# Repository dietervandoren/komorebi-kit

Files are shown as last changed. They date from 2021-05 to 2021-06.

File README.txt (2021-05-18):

//~~~~~~~~~~~~~~~~~~~~~~~~~~~~~~~~~~~~~~~~~~~~~~~~~~~~~~~~~~~~~~~~~~~~~~~~~~~~~
//
// KOMOREBI KIT, 2021 
//
// Created by Matteo Marangoni & Dieter Vandoren 
// Programming by Riccardo Marogna
// PCB design by Daan Johan 
//
// Info & documentation: https://instrumentinventors.org/editions/iii-sensory-kit-komorebi-instructions/ 
// GitHub: https://github.com/dietervandoren/komorebi-kit 
//
// KOMOREBI KIT is licensed under a Creative Commons Attribution-NonCommercial-ShareAlike 4.0 International License, 
// which is detailed in License.txt 
//
// KOMOREBI KIT includes the Mozzi sound synthesis library under a Creative Commons Attribution-NonCommercial-ShareAlike 4.0 International License.
// Mozzi is created by Tim Barrass, webpage: https://sensorium.github.com/Mozzi/ 
// 
//~~~~~~~~~~~~~~~~~~~~~~~~~~~~~~~~~~~~~~~~~~~~~~~~~~~~~~~~~~~~~~~~~~~~~~~~~~~~~

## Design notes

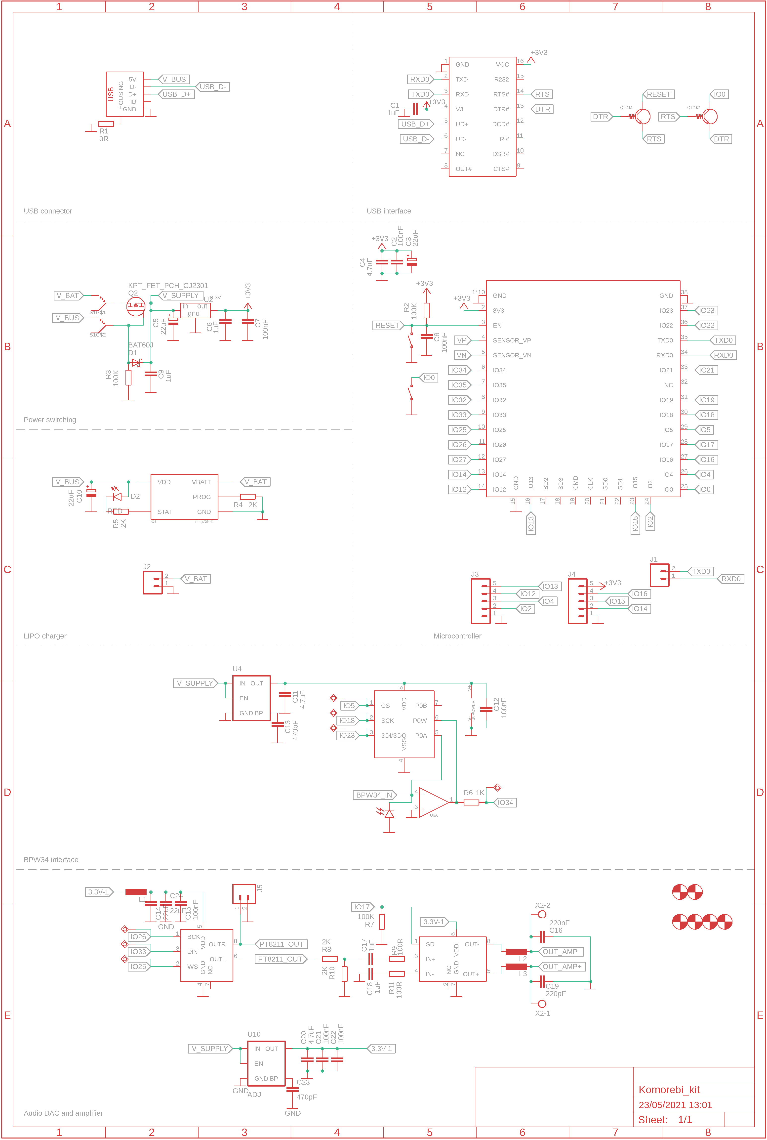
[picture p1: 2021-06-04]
PCB/Komorebi_Kit_final_SCHIMG.png

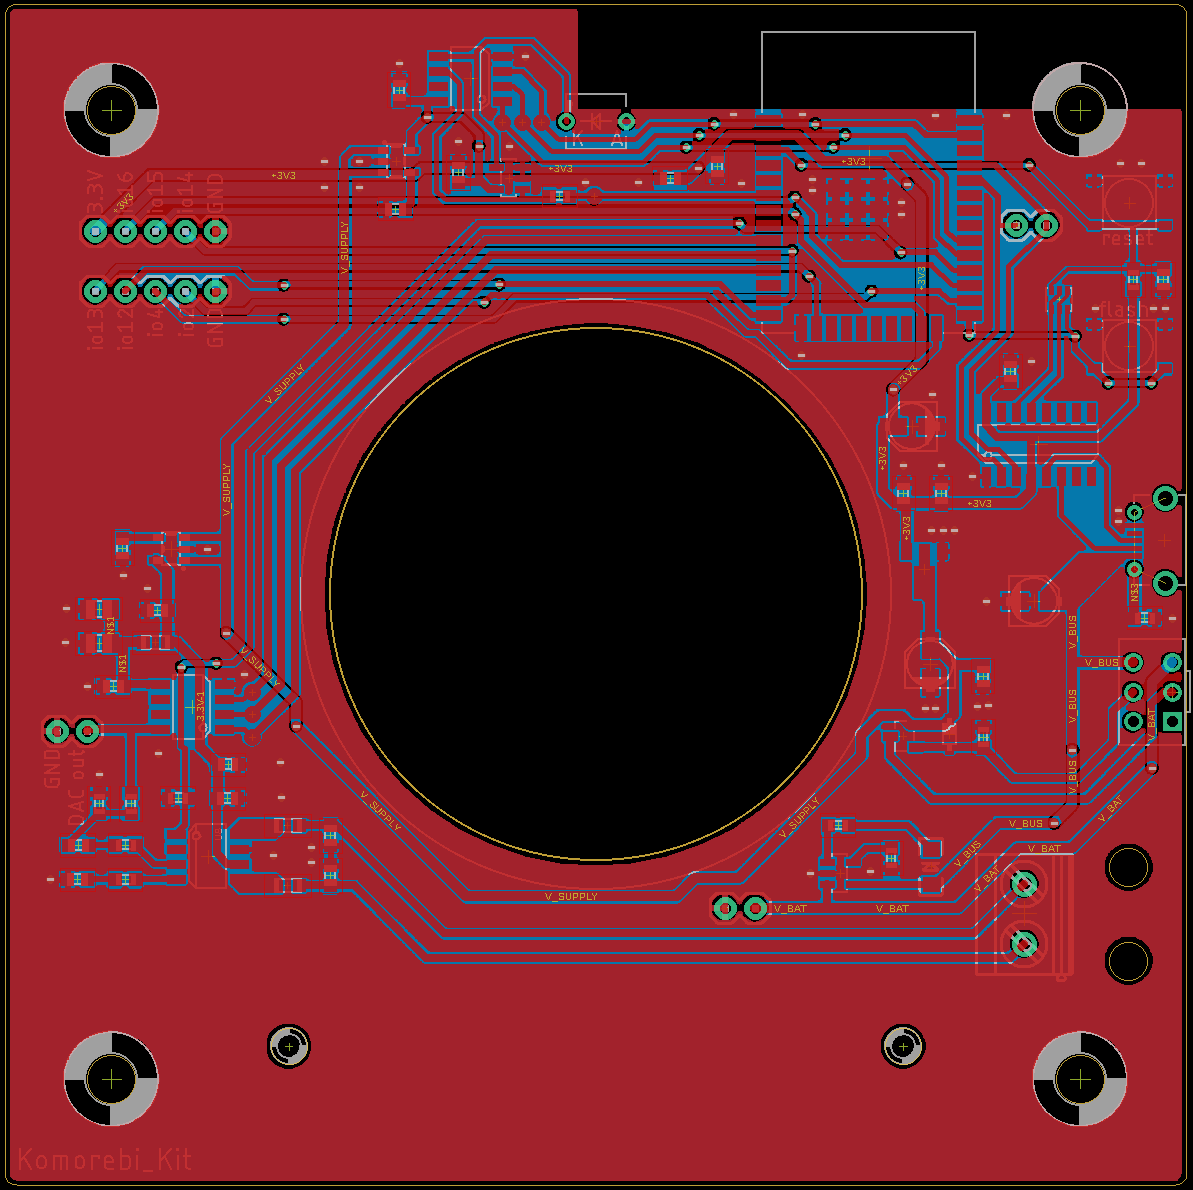
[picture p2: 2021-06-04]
PCB/Komorebi_Kit_final_BRDIMG.png

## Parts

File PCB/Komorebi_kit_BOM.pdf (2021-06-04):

Blad1_2

Value | Designator | Package
0R | R1 | R0603
100K | R2, R3, R7 | R0603
2K | R4, R5, R8, R10 | R0603
1K | R6 | R0603
100R | R9, R11 | R0603
1uF | C1, C6, C9, C17, C18 | C0603
100nF | C2, C7, C8, C12, C15, C21, C22 | C0603
22uF | C3, C5, C10 | ECAP-4x5.3
4.7uF | C4, C11, C20 | C0603
470pF | C13, C23 | C0603
22uF | C14, C24 | C0805
220pF | C16, C19 | C0603
| L1, L2, L3 | L0805
BAT60J | D1 | SOD323_ST
RED | D2 | LED-1206
UMH3N | Q1 | SOT363
CJ2301 | Q2 | SOT23
MCP73831 | IC1 | SOT23-5
CH340C | U1 | SOIC16
HT7388 | U2 | SOT-89-3L
ESP32 | U3 | SMD_38_EP
MIC5202 | U4, U10 | SOT23-5
MCP4151 | U5 | SOIC-8
MCP6001 | U6 | SOT23-5
TM8211 | U7 | SOIC-8
PAM8302 | U8 | SOIC-8
TS-1187A-B-A-B | S2, S3 | SMD-SW
920-E52A2021S10100 | X1 | SMD

Blad1_2

Pagina

2

C21189
C25803
C22975
C21190
C22775
C29936
C83054
C134721
C354262
C107062
C45783
C1603
C85835
C514095
C84270
C62892
C8547
C424093
C84681
C50936
C473012
C37970
C185602
C29429
C92003
C112137
C318884
C10418

LCSC
ordernr.

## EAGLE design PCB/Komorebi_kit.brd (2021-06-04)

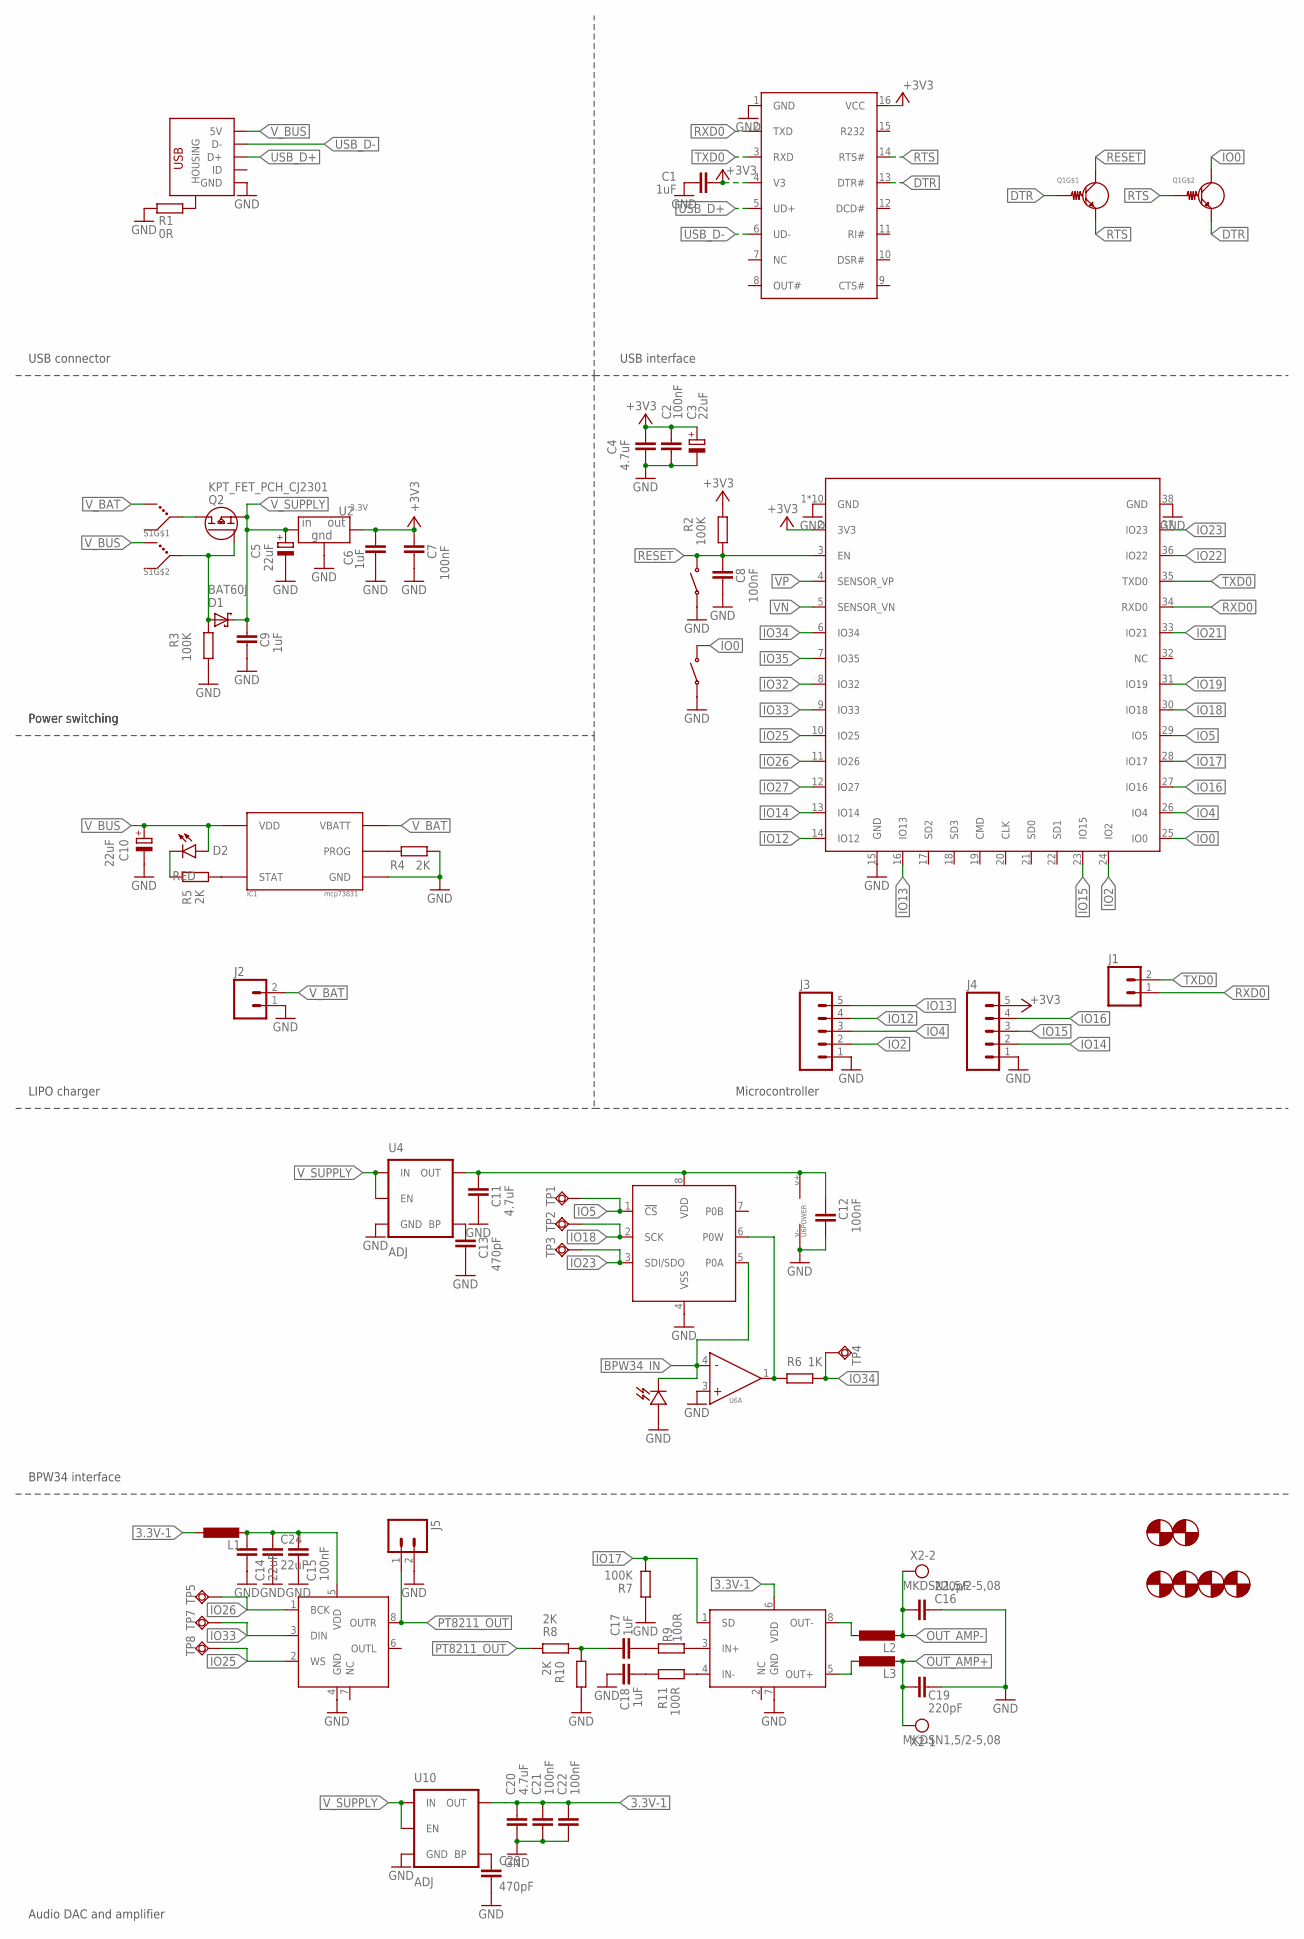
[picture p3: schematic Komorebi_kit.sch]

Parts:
C1, C6, C9, C17, C18: 1uF; C0603
C2, C7, C8, C12, C15, C21, C22: 100nF; C0603
C3, C5, C10: 22uF; PANASONIC_B
C4, C11, C20: 4.7uF; C0603
C13, C23: 470pF; C0603
C14, C24: 22uF; C0805
C16, C19: 220pF; C0603
D1: BAT60J; SOD323_ST
D2: RED; LED-1206
D3: KPT_SENSORS_BPW34; BPW34
H1, H2: KPT_HOLE3.0; 3.0MOUNTHOLE
H3, H4, H5, H6: KPT_HOLE4.1; 4.1MOUNTHOLE
IC1: KPT_CHARGER_MCP73831; SOT23-5
J1, J2, J5: M02PTH; 1X02
J3, J4: M05PTH; 1X05
L1, L2, L3: L-EUL2012C; L2012C
Q1: KPT_UMH3N; SOT363
Q2: KPT_FET_PCH_CJ2301; SOT23
R1: 0R; R0603
R2, R3, R7: 100K; R0603
R4, R5, R8, R10: 2K; R0603
R6: 1K; R0603
R9, R11: 100R; R0603
S1: KPT_SWITCH_JS202011AQN; C&K_JS202011AQN
S2, S3: TACT_SWITCH_C318884; SWITCH_TACTILE_C318884
TP1, TP2, TP3, TP4, TP5, TP7, TP8: TPSQB1,27; B1,27
U1: KPT_CH340C; SOIC16
U2: 3.3V; SOT-89-3L
U3: KPT_ESP32; WROOM_ESP32
U4, U10: ADJ; SOT23-5
U5: KPT_DIGIPOT_MCP41X1SOIC8; SOIC-8
U6: KPT_OPAMP_MCP6001; SOT23-5
U7: KPT_DAC_PT8211; SOIC-8
U8: KPT_AMP-D_PAM8302SOIC8; SOIC-8
X1: USB_MICROB_C10418
X2: MKDSN1,5/2-5,08

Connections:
3.3V-1: C20.1, C21.1, C22.1, L1.1, U8.6 (VDD), U10.5 (OUT)
+3V3: C1.2, C2.1, C3.+, C4.2, C6.1, C7.1, J4.5, R2.2, U1.4 (V3), U1.16 (VCC), U2.P$3 (OUT), U3.2 (3V3)
BPW34_IN: D3.CATHODE, U5.5 (P0A), U6.4 (-)
DTR: Q1.2 (BASE), Q1.4 (EMITTER), U1.13 (DTR#)
GND: C1.1, C2.2, C3.-, C4.1, C5.-, C6.2, C7.2, C8.2, C9.2, C10.-, C11.2, C12.2, C13.2, C14.2, C15.2, C16.1, C18.1, C19.1, C20.2, C21.2, C22.2, C23.2, C24.2, D3.ANODE, IC1.2 (GND), J2.1, J3.1, J4.1, J5.2, R1.1, R3.1, R4.2, R7.1, R10.1, S2.A, S2.B, S3.A, S3.B, U1.1 (GND), U2.P$1 (GND), U3.1 (GND), U3.15 (GND), U3.38 (GND), U3.BP1 (GND), U3.BP2 (GND), U3.BP3 (GND), U3.BP4 (GND), U3.BP5 (GND), U3.BP6 (GND), U3.BP7 (GND), U3.BP8 (GND), U3.BP9 (GND), U4.2 (GND), U5.4 (VSS), U6.2 (V-), U6.3 (+), U7.4 (GND), U8.7 (GND), U10.2 (GND), X1.P$1 (GND)
IN_AMP1: C17.1, R8.2, R10.2
IO0: Q1.3 (COLLECTOR), S3.C, S3.D, U3.25 (IO0)
IO2: J3.2, U3.24 (IO2)
IO4: J3.3, U3.26 (IO4)
IO5: TP1.TP, U3.29 (IO5), U5.1 (!CS!)
IO12: J3.4, U3.14 (IO12)
IO13: J3.5, U3.16 (IO13)
IO14: J4.2, U3.13 (IO14)
IO15: J4.3, U3.23 (IO15)
IO16: J4.4, U3.27 (IO16)
IO17: R7.2, U3.28 (IO17), U8.1 (SD)
IO18: TP2.TP, U3.30 (IO18), U5.2 (SCK)
IO19: U3.31 (IO19)
IO21: U3.33 (IO21)
IO22: U3.36 (IO22)
IO23: TP3.TP, U3.37 (IO23), U5.3 (SDI/SDO)
IO25: TP8.TP, U3.10 (IO25), U7.2 (WS)
IO26: TP5.TP, U3.11 (IO26), U7.1 (BCK)
IO27: U3.12 (IO27)
IO32: U3.8 (IO32)
IO33: TP7.TP, U3.9 (IO33), U7.3 (DIN)
IO34: R6.1, TP4.TP, U3.6 (IO34)
IO35: U3.7 (IO35)
unnamed: C14.1, C15.1, C24.1, L1.2, U7.5 (VDD)
unnamed: C11.1, C12.1, U4.5 (OUT), U5.8 (VDD), U6.5 (V+)
unnamed: R1.2, X1.P$6 (HOUSING), X1.P$7 (HOUSING), X1.P$8 (HOUSING), X1.P$9 (HOUSING)
unnamed: C17.2, R9.1
unnamed: C18.2, R11.1
unnamed: R9.2, U8.3 (IN+)
unnamed: IC1.5 (PROG), R4.1
unnamed: R11.2, U8.4 (IN-)
unnamed: C23.1, U10.4 (BP)
unnamed: L2.1, U8.8 (OUT-)
unnamed: L3.1, U8.5 (OUT+)
unnamed: D1.A, Q2.1 (G), R3.2, S1.P$5 (COM)
unnamed: Q2.3 (D), S1.P$2 (COM)
unnamed: D2.C, R5.1
unnamed: C13.1, U4.4 (BP)
unnamed: IC1.1 (STAT), R5.2
unnamed: R6.2, U5.6 (P0W), U6.1 (OUT)
OUT_AMP+: C19.2, L3.2, X2.1
OUT_AMP-: C16.2, L2.2, X2.2
PT8211_OUT: J5.1, R8.1, U7.8 (OUTR)
RESET: C8.1, Q1.6 (COLLECTOR), R2.1, S2.C, S2.D, U3.3 (EN)
RTS: Q1.1 (EMITTER), Q1.5 (BASE), U1.14 (RTS#)
RXD0: J1.1, U1.2 (TXD), U3.34 (RXD0)
TXD0: J1.2, U1.3 (RXD), U3.35 (TXD0)
USB_D+: U1.5 (UD+), X1.P$3 (D+)
USB_D-: U1.6 (UD-), X1.P$4 (D-)
VN: U3.5 (SENSOR_VN)
VP: U3.4 (SENSOR_VP)
V_BAT: IC1.3 (VBATT), J2.2, S1.P$3 (SW_ACTION)
V_BUS: C10.+, D2.A, IC1.4 (VDD), S1.P$6 (SW_ACTION), X1.P$5 (5V)
V_SUPPLY: C5.+, C9.1, D1.C, Q2.2 (S), U2.P$2 (IN), U2.P$4 (IN), U4.1 (IN), U4.3 (EN), U10.1 (IN), U10.3 (EN)

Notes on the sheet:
USB connector
USB interface
Power switching
LIPO charger
Microcontroller
BPW34 interface
Audio DAC and amplifier

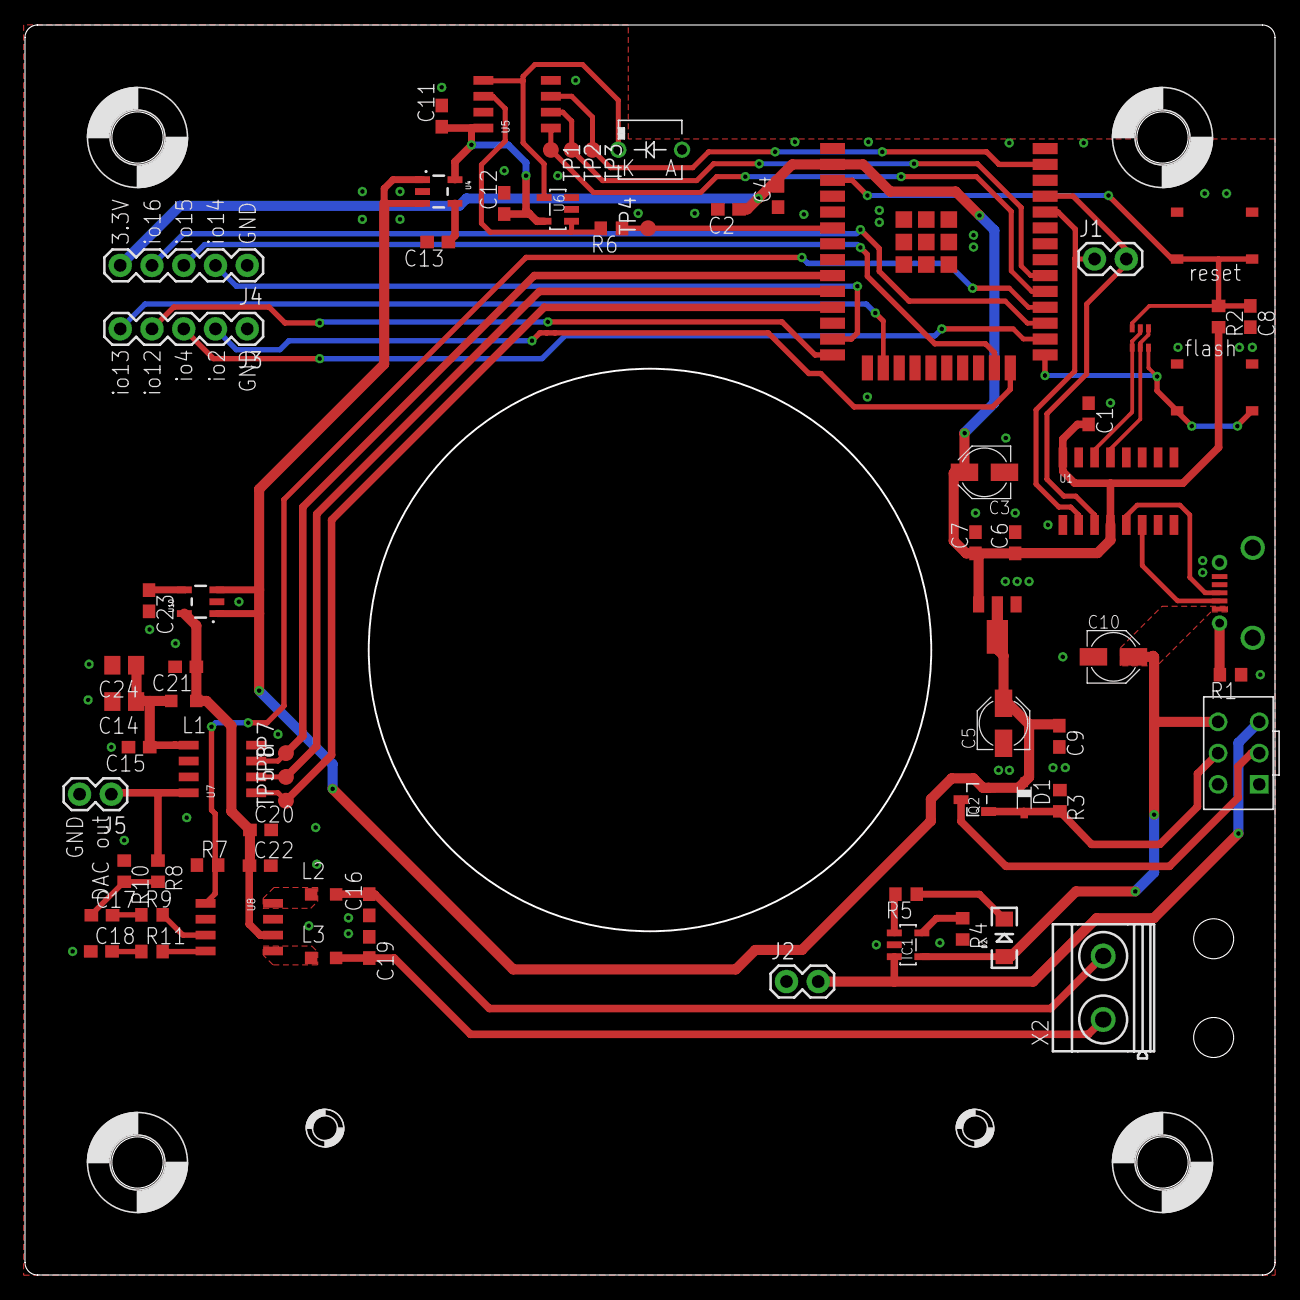
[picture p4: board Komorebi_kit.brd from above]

Board: 2 copper layers, 100.0 x 100.0 mm, 76 parts (0 on the bottom side), 51 nets.

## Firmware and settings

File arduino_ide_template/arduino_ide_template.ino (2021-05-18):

// Minimal sketch to demonstrate programming the Komorebi Kit hardware using the Arduino IDE and Mozzi library
// 
// Dieter Vandoren & Matteo Marangoni, 2021
//
// Project info & documentation: https://instrumentinventors.org/editions/iii-sensory-kit-komorebi-instructions/ 


// Mozzi synthesis library
#include <MozziGuts.h>
#include <Oscil.h> 
#include <tables/sin2048_int8.h> // sine wavetable for oscillator
Oscil <SIN2048_NUM_CELLS, AUDIO_RATE> aSin(SIN2048_DATA); // create oscillator object
#define CONTROL_RATE 64 // 64Hz control rate 

// amplifier enable output pin
const int ampPin = 17;

// light sensor input pin 
const int lightPin = 34;

// variable to store light input value
int lightValue; 

// light input pre-amplification: gain is set using a digital potentiometer via SPI protocol
#include <SPI.h>
const int slaveSelectPin = 5;
int lightGain = 127;  // gain value setting, [0-255] range is reversed:
                      //    0 = maximum gain (twilight, candle light)
                      //    255 = minimum gain (direct sunlight)
                      // use serial monitor to check whether light input values are in a useful range
                      // the input ADC has 12 bit resolution meaning values can be between 0 and 4095 
                      // if input values are stuck at 0 turn up the gain by lowering the lightGain value
                      // if input values are stuck at 4095 turn down gain by raising the lightGain value
                  
// variable for sine oscillator frequency
float sineFreq = 600.f;


void setup(){
  // start serial interface
  Serial.begin(9600);
  while(!Serial){};

  // init light input gain control
  pinMode(slaveSelectPin, OUTPUT);
  SPI.begin();
  // set gain value
  digitalPotWrite(0, lightGain); 

  // light input
  pinMode(lightPin, INPUT);
  
  // amplifier enable, required if audio output via the amplifier and speaker circuit is to be used
  pinMode(ampPin, OUTPUT);
  digitalWrite(ampPin, HIGH);

  // start Mozzi synthesis process
  startMozzi(CONTROL_RATE); 

  // set initial sine oscillator frequency
  aSin.setFreq(sineFreq); 
}


void updateControl(){
  // slow control rate calculations in here: (do the heavy lifting here)

  // read & print light input
  lightValue = analogRead(lightPin);
  Serial.println(lightValue);

  // map light input [0, 4095] to sine frequency range [600, 2500]
  sineFreq = map(lightValue, 0, 4095, 600, 2500);

  // set new frequency
  aSin.setFreq(sineFreq);
}


int updateAudio(){
  // fast audio rate calculations in here: (keep this slim and fast, no serial printing!)
  
  int sig = aSin.next(); // get next sine wave value
  
  return sig << 4; // return calculated sample value to audio output buffer
                   // fast output amplitude modification by bitshifts: 
                   //   1 bitshift left/up doubles the amplitude 
                   //   1 bitshift right/down halves the amplitude  
                   // output must not exceed 16 bit maximum, ie. 65535, or digital clipping will occur
}


void loop(){
  audioHook(); // Call Mozzi audioHook() process in loop(). 
               // Put all other operations in the slower updateControl() function 
               // unless strictly necessary to run at loop() frequency, 
               // to save processor cycles for audio processing.
}


void digitalPotWrite(int address, int value) {
  // SPI interface to digital pot for setting light input gain
  
  // take the SS pin low to select the chip:
  digitalWrite(slaveSelectPin, LOW);
  delay(10);
  //  send in the address and value via SPI:
  SPI.transfer(address);
  SPI.transfer(value);
  delay(10);
  // take the SS pin high to de-select the chip:
  digitalWrite(slaveSelectPin, HIGH);
}

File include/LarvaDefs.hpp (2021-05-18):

//~~~~~~~~~~~~~~~~~~~~~~~~~~~~~~~~~~~~~~~~~~~~~~~~~~~~~~~~~~~~~~~~~~~~~~~~~~~~~
//
// KOMOREBI KIT, 2021 
//
// Created by Matteo Marangoni & Dieter Vandoren 
// Programming by Riccardo Marogna
// 
//~~~~~~~~~~~~~~~~~~~~~~~~~~~~~~~~~~~~~~~~~~~~~~~~~~~~~~~~~~~~~~~~~~~~~~~~~~~~~

//~~~~~~~~~~~~~~~~~~~~~~~~~~~~~~~~~~~~~~~~~~~~~~~~~~~~~~~~
// Main parameter definitions
//~~~~~~~~~~~~~~~~~~~~~~~~~~~~~~~~~~~~~~~~~~~~~~~~~~~~~~~~

#pragma once

#include "MozziGuts.h"

//#define PRINT

enum ChordID { 
    kChord1=0,
    kChord2,
    kChord3,
    kChord4,
    kChord5,

    kNumChords
};


// Chords defs

// fundameltals (circle of 5ths)
const float Fund1 = 110.;
const float Fund2 = Fund1/2*3;
const float Fund3 = (Fund2/2*3)/2;
const float Fund4 = Fund3/2*3;
const float Fund5 = (Fund4/2*3)/2;

static const float cChord1[5] = {
Fund1,
Fund1/4*5, //(5:4)
Fund1/2*3, //(3:2)
Fund1/3*5, // (5:3)
Fund1*2
};

static const float cChord2[5] = {
Fund2,
Fund2/4*5, 
Fund2/2*3, 
Fund2/3*5,
Fund2*2
};

static const float cChord3[5] = {
Fund3,
Fund3/4*5, 
Fund3/2*3, 
Fund3/3*5,
Fund3*2
};

static const float cChord4[5] = {
Fund4,
Fund4/4*5, 
Fund4/2*3, 
Fund4/3*5,
Fund4*2
};

static const float cChord5[5] = {
Fund5,
Fund5/4*5, 
Fund5/2*3, 
Fund5/3*5,
Fund5*2
};

static const float* cChords[kNumChords] = {
    cChord1,
    cChord2,
    cChord3,
    cChord4,
    cChord5,
};

// num strings for each Chord
static const int cNumStrings = 3;

// num partials for each string
static const int cNumPartials = 12;

// max random offset from which to start sounding partials above the fundamental
static const int MaxTuningOffset = 3; // tested 0-3

// when tuning the 3 strings we randomly pick between one of these voicing options:

static const int cNumChordVoicings = 5;
static const int cChordVoicings[cNumChordVoicings][cNumStrings] = {
    { 0, 1, 2 },
    { 0, 1, 3 },
    { 0, 2, 3 },
    { 0, 2, 4 },  
    { 1, 3, 4 },
};


//~~~~~~~~~~~~~~~~~~~~~~~~~~~~~~~~~~~~~~~~~~~~~~~~~~~~~~~~~~~~~~~~~~
// DRONES SETTINGS

static const int TMul = 15;
static constexpr float cDroneMasterGain = 2.5f;

// mod gain vs freq
const float cFreqCutoff = 300.f; // gain of freqs above this cutoff is scaled
const float cFreqMax = 6000.f;  // freq at which gain will be min
const float cGainHF = 0.001f;    // min gain

// slope of the gain curve (<1 valle, >1 monte) 
// range (0.25--3.0)
const float cGainSlope = 0.8f;  


// max playing time duration ms before resetting cutoff partial
static const unsigned long cDroneMaxDurMs = 4000;

// detune factor, normalized
static const float cDetuneFactor = 0.01f;

// LFO on detune
static const float cLFOrate[cNumStrings] = { 0.10f, 0.045f, 0.06f }; // 0.5f, 0.17f, 0.23f 
static const int cLFOsr = 6; // lfo samplerate
static const int cLFOUpdateInterval = CONTROL_RATE / cLFOsr;

// drone gain smoothing factor
static const float gcSmoothness = 0.975f; 

static const int cDroneStartThres = 10*TMul;
static const int cDroneRange[cNumStrings] = { 1100*TMul, 1100*TMul, 1100*TMul};

static const int cDroneDecreaseStep[cNumStrings] = { 5*TMul, 6*TMul, 7*TMul };
static const int cDroneDecreaseRate = 20; // ms

// Decrease step mult factor vs freq curve
const float cDecrCutoff = 800.f;    // decrease step of freqs above this cutoff is scaled
const float cDecrFreqMax = 6000.f;  // freq at which gain will be min
const float cDecrHF = 0.1f;         // decrease step factor @ max freq 1= no effect, < 1 damps higher freqs
const float cDecrSlope = 0.8f;      // slope (<1 valle, >1 monte)  


// partial gain
static const int gain_max = 255;
static const int gain_min = 0;

//~~~~~~~~~~~~~~~~~~~~~~~~~~~~~~~~~~~~~~~~~~~~~~~~~~~~~~~~~~~~~~~~~~
// PLOKS SETTINGS

static const int cPlokImpulseDurMin = 10;
static const int cPlokImpulseDurRange = 20;

static const float cPlokDurEstimMs = 50.f;

static constexpr float cPulseGainL = 14.f;
static constexpr float cPulseGainM = 6.f;
static constexpr float cPulseGainS = 2.f;

/*
Pulse resonance instead can be mapped to “excursion” (as mentioned before) - 
the range for the resonance parameter that sounds good is 10-60 (as in Riccardo’s defs), 
a small range of randomness here is nice (for instance a random range of +-5).  
Excursion is defined as the difference between min and max light input value in the last period (try 60 secs). 
Excursion is then mapped to the resonance value (15-55 +- random5) again following a bell shaped curve 
(same as described above with pulse loudness relative to trigger count, 
also here we need to tune the bell curve to a good range while testing). 
*/
static const int cLightExcursionIntervalSecs = 60;  // in seconds
static const float cLightExcursionMin = 0.f;        // on absolute light range (scaled)
static const float cLightExcursionMax = 300.f;     // on absolute light range (scaled)
static const float cPulseResonanceMin = 20.f;
static const float cPulseResonanceMax = 50.f;
static const float cPulseResonanceRandRange = 5.f;
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

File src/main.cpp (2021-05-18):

//~~~~~~~~~~~~~~~~~~~~~~~~~~~~~~~~~~~~~~~~~~~~~~~~~~~~~~~~~~~~~~~~~~~~~~~~~~~~~
//
// KOMOREBI KIT, 2021 
//
// Created by Matteo Marangoni & Dieter Vandoren 
// Programming by Riccardo Marogna
// 
//~~~~~~~~~~~~~~~~~~~~~~~~~~~~~~~~~~~~~~~~~~~~~~~~~~~~~~~~~~~~~~~~~~~~~~~~~~~~~

#include "LarvaDefs.hpp"
#include "PhotoSensReader.hpp"
#include "LarvaSynth2.hpp"

LarvaSynth2 mSynth;
PhotoSensReader mPhotoSensReader;

void setup()
{
  #ifdef PRINT
  Serial.begin(9600);
  while(!Serial);
  #endif

  // amp enable
  pinMode(cAmpEnablePin, OUTPUT);
  digitalWrite(cAmpEnablePin, HIGH);
  
  mPhotoSensReader.Init();
  mSynth.Init();
  mSynth.Start();
}

void updateControl(){
  mPhotoSensReader.Update();  
  int vluxraw = mPhotoSensReader.GetLuxRaw();
  int vluxscaled = mPhotoSensReader.GetLuxScaled();
  mSynth.Update( vluxraw, vluxscaled );
}

int updateAudio(){
  return mSynth.Process();
  //return 0;
}

void loop(){  
  audioHook();
}

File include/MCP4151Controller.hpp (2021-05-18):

//~~~~~~~~~~~~~~~~~~~~~~~~~~~~~~~~~~~~~~~~~~~~~~~~~~~~~~~~~~~~~~~~~~~~~~~~~~~~~
//
// KOMOREBI KIT, 2021 
//
// Created by Matteo Marangoni & Dieter Vandoren 
// Programming by Riccardo Marogna
// 
//~~~~~~~~~~~~~~~~~~~~~~~~~~~~~~~~~~~~~~~~~~~~~~~~~~~~~~~~~~~~~~~~~~~~~~~~~~~~~

//~~~~~~~~~~~~~~~~~~~~~~~~~~~~~~~~~~~~~~~~~~~~~~~~~~~~~~~~
// MCP4151 digital pot Controller
//~~~~~~~~~~~~~~~~~~~~~~~~~~~~~~~~~~~~~~~~~~~~~~~~~~~~~~~~

#pragma once

#include <SPI.h>
#include "Arduino.h"
#include "LarvaDefs.hpp"

class MCP4151Controller
{

public:
    MCP4151Controller(){}
    ~MCP4151Controller(){}

    // init @ setup
    void Init(){
        pinMode(slaveSelectPin, OUTPUT); //??
        SPI.begin();
        digitalPotWrite(0, 0); // initial value
    }

    void SetGain( const int acGain ){
        int val = acGain;
        val = val>255 ? 255 : val;
        val = val<0 ? 0 : val;
        mGain = val;

        // note: pot/gain is inverse
        int pot = 255 - mGain;
        digitalPotWrite(0, pot);
    }

    int GetGain(){ return mGain; }

    // Write to digital pot to control photosensor amp
    void digitalPotWrite(int address, int value) 
    {
        // take the SS pin low to select the chip:
        digitalWrite(slaveSelectPin, LOW);
        
        //  send in the address and value via SPI:
        SPI.transfer(address);
        SPI.transfer(value);
        
        // take the SS pin high to de-select the chip:
        digitalWrite(slaveSelectPin, HIGH);
    }

private:
    const int slaveSelectPin = 5;

    // 0...255
    int mGain{0};

    unsigned long mPrevTimeStampMs{0};
};

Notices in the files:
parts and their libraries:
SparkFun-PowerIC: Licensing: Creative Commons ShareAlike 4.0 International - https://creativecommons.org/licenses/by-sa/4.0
